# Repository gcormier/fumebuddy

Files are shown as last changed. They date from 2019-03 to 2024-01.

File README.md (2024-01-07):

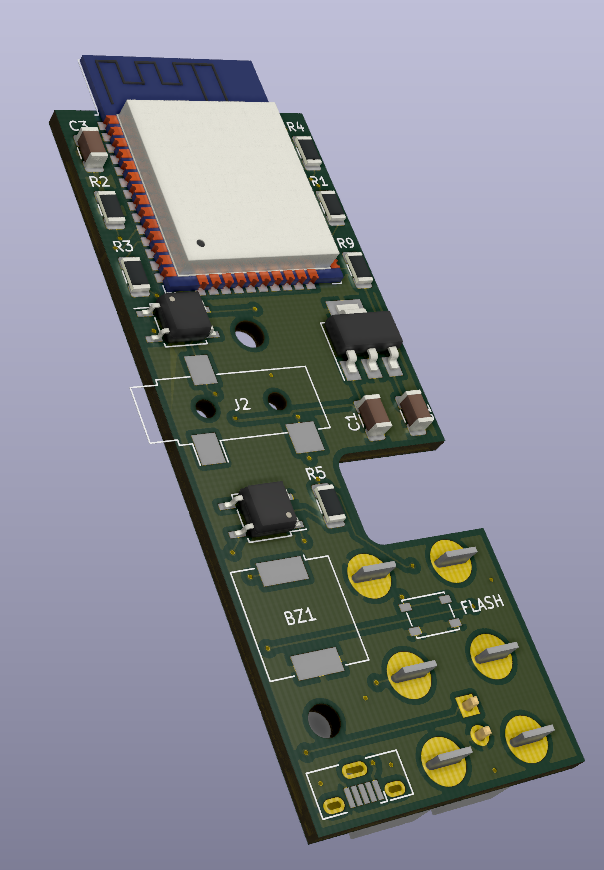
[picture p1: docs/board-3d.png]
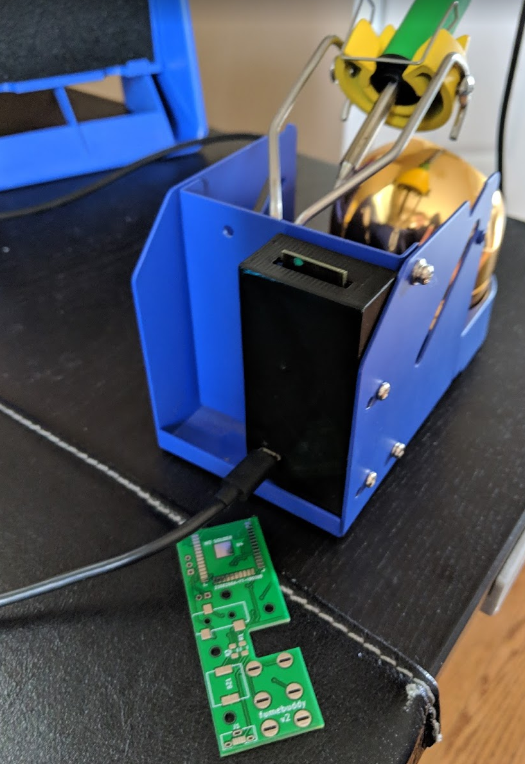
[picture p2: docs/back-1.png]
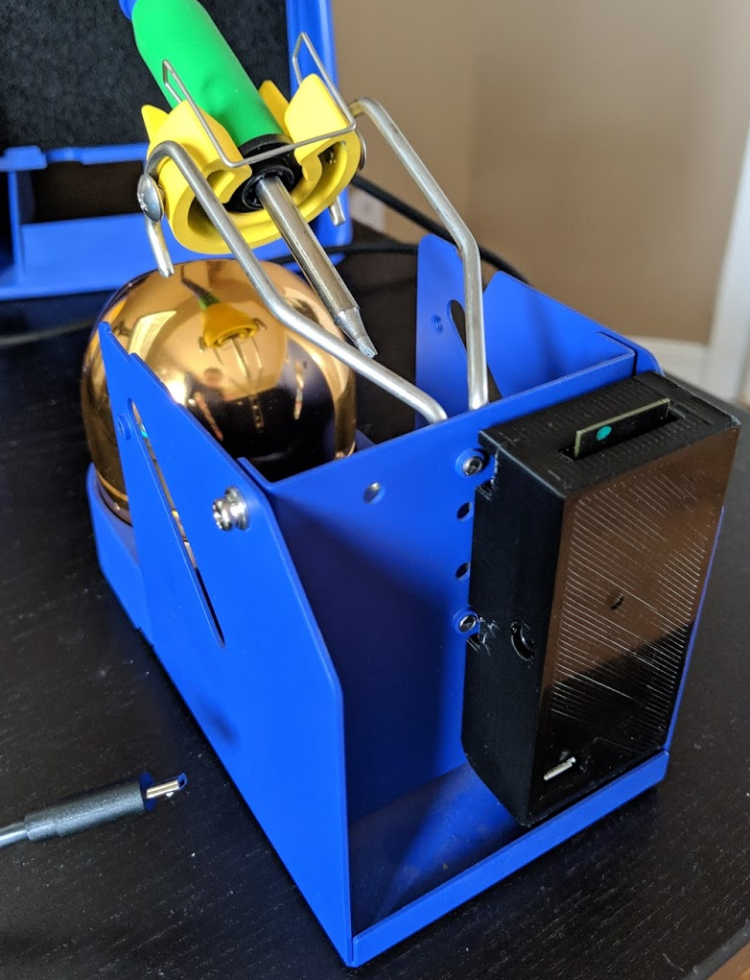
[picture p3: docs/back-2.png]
  

# FumeBuddy
FumeBuddy is an ESP32 replacement for the switch housing on the Hakko FX-950, FX-951 and FX-952. Out of the box, it was designed to toggle a fume extractor via a smart switch flashed with [Tasmota](https://tasmota.github.io/docs/#/). It is powered via USB, which allows it to be powered by a battery pack if desired.



## Design Goals
- Easily hacked
- Replace stock housing
- Default behavior when un-powered

## Video
[See FumeBuddy explained and in action](https://www.youtube.com/watch?v=eo5WyHWy1So)

## Hardware Installation
- Remove the old housing
- Transfer the spring from the old housing to the new housing
- Install using the old screws
- If you'd like the manual capacitive touch function and did not order it, you can solder a single wire to the appropriate jumper

## Configuration
FumeBuddy now uses [esphome](https://esphome.io/index.html). You don't need Home Assistant or any sort of smart home. It merely eliminates the need for me to do any custom coding.

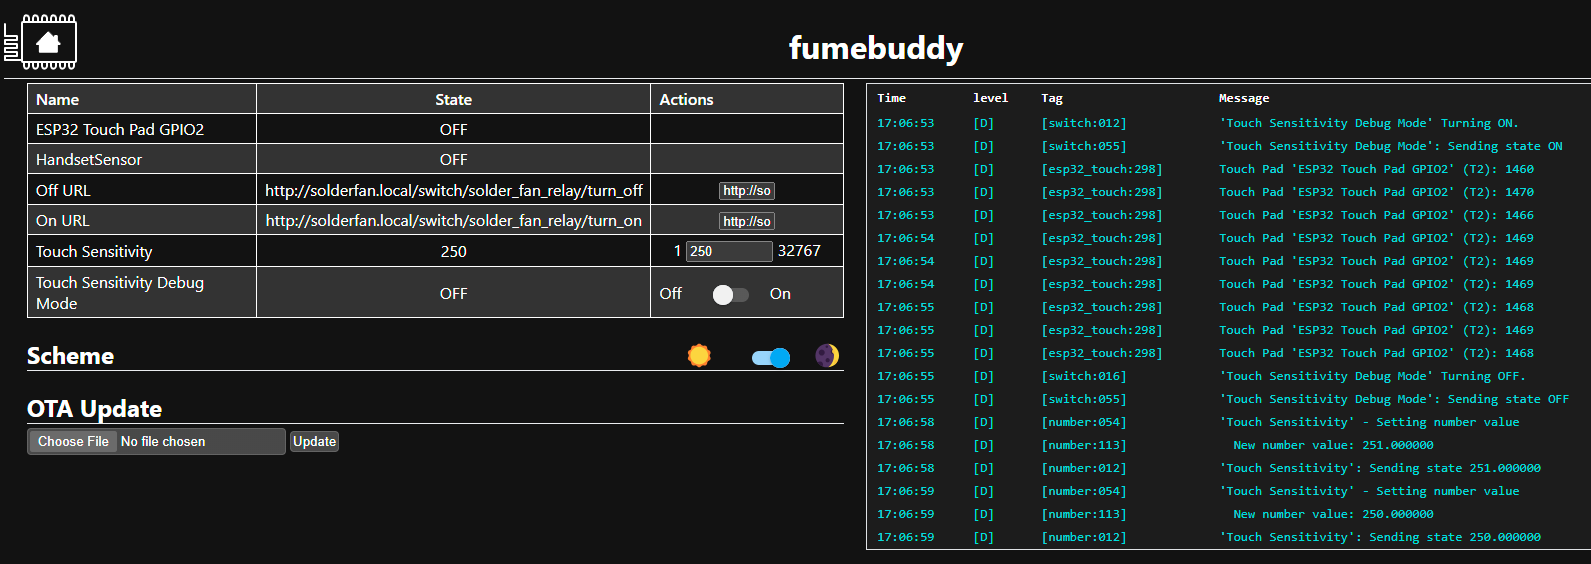
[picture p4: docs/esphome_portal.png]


When you plug in the device, it will create it's own WiFi access point named `FumebuddyFallback` (Password is `fumebuddy`). You
can connect to this and it will redirect you to a captive portal where you can enter your WiFi credentials. Once you do this, it will reboot and connect to your WiFi. You can then access it via the IP address it was assigned by your router.

Accessing it via the IP address will give you a web interface where you can configure the device. Notably the 2 URL's that should be called when the iron is lifted and put back down.

The touch sensor threshold can be adjusted. The default is 250, but you can enable the sensitivity debug mode and view the output
in the web console to see which value works best for you.

## Operation
- If FumeBuddy is NOT powered, the iron will work as it did before with sleep function
- If FumeBuddy is powered via the 5V USB port, it will work based on what is programmed. By default, it will turn the plug ON when the iron is lifted. It will turn the plug OFF 5 seconds after the iron is put back
- Manual on/off can be by touching and holding the capacitive wire on top of the housing. It will keep the fan on until you touch it again.

## Pricing
The BOM cost alone for the product is around 23USD, which is rather expensive. I order **genuine** parts from 1st party distributors in Canada, which in this case includes Omron switches, solid state relays and the ESP32. I did not go cheap on this as owners of Hakko's are likely looking for quality components throughout. The rest includes my labor costs to assembly, flash and test the unit. As it is open sourced, you are welcome to build your own! You can cheap out on some components if you'd like. Knockoff relays and omitting the audio buzzer will save you a few dollars.

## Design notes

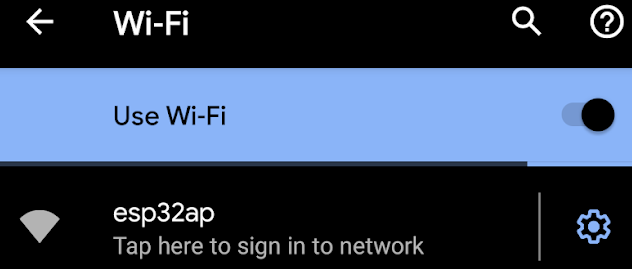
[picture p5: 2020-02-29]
docs/esp32ap-signin.png

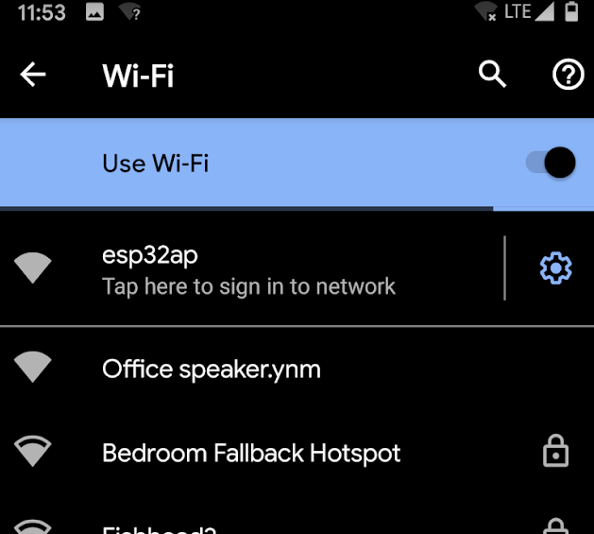
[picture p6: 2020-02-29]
docs/esp32ap.png

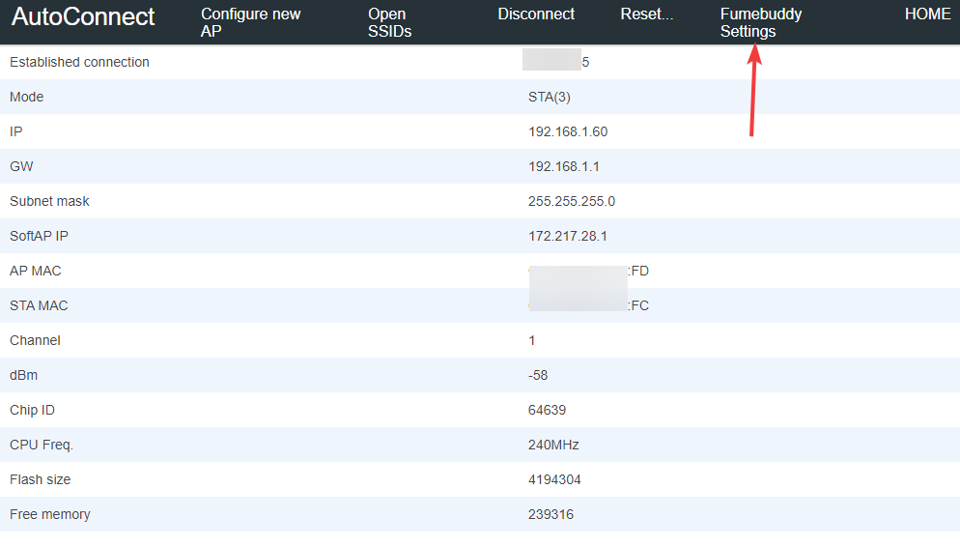
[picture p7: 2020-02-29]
docs/tasmota_1.png

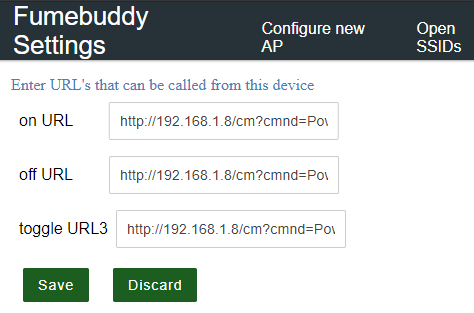
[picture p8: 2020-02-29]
docs/tasmota_2.png

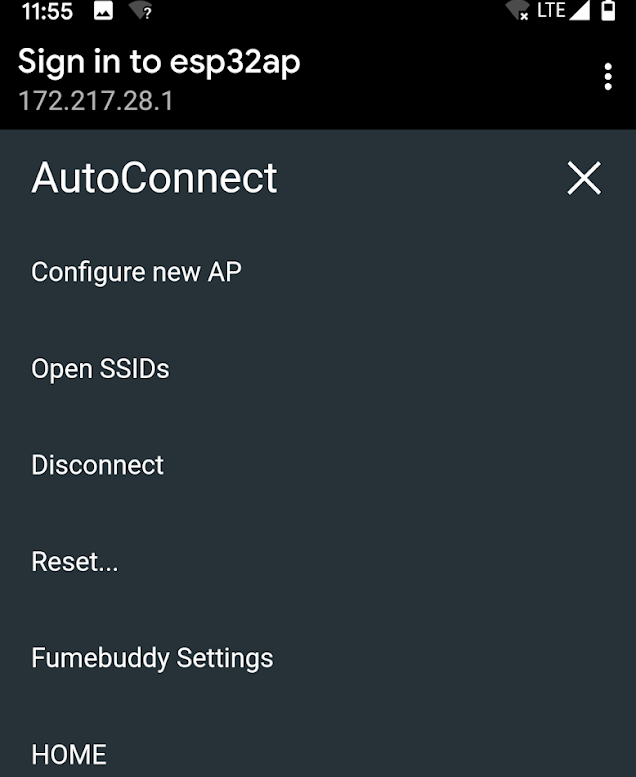
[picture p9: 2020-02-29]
docs/esp32-setting.png

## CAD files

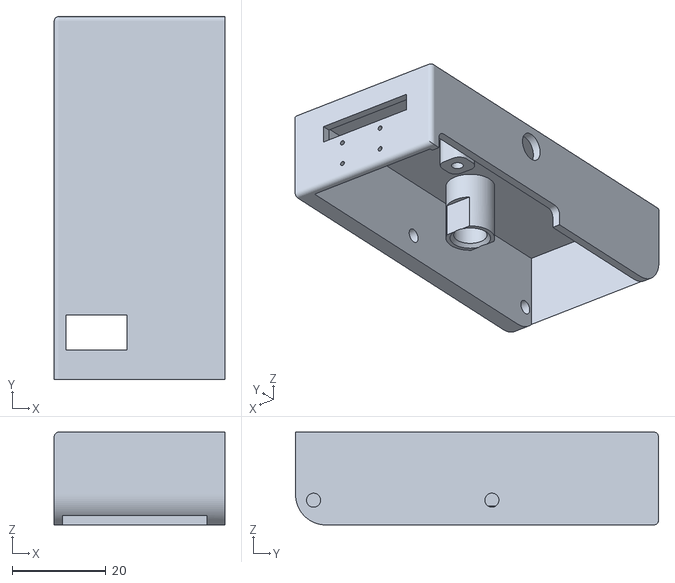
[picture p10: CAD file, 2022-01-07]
Case.stl
36.3 x 77.4 x 19.8

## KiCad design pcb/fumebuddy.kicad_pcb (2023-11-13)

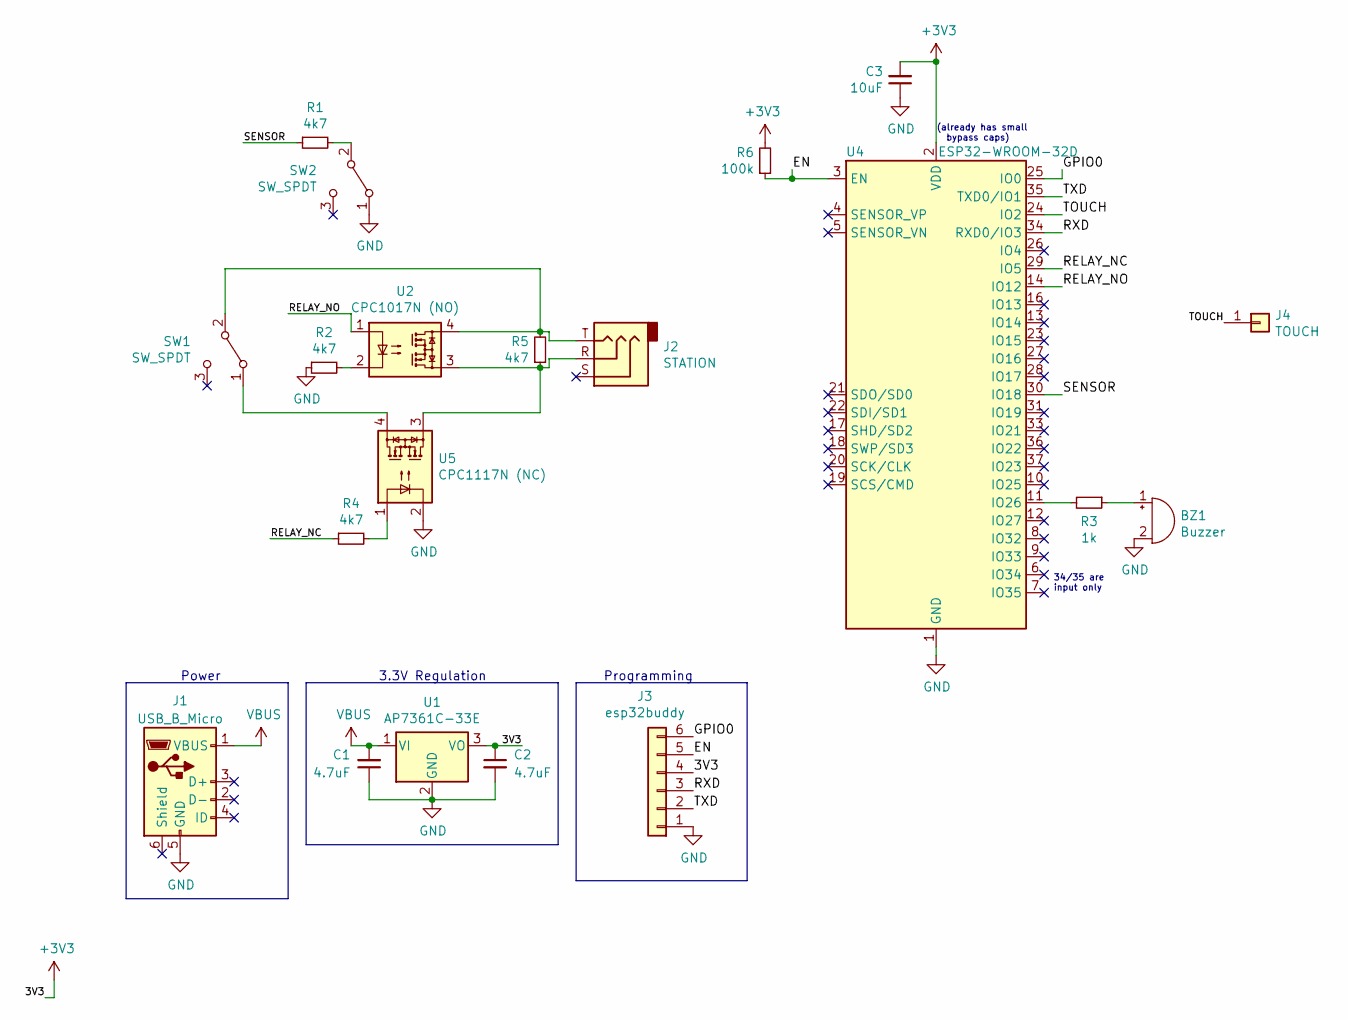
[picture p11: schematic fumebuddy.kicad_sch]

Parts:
BZ1: Buzzer; Buzzer_CUI_CPT-9019S-SMT
C1, C2: 4.7uF; C_1206_3216Metric
C3: 10uF; C_1206_3216Metric
J1: USB_B_Micro; USB_Micro-B_Molex-105133-0001
J2: STATION; Jack_3.5mm_CUI_SJ-3523-SMT_Horizontal
J3: esp32buddy; PinHeader_1x06_P2.54mm_Vertical
J4: TOUCH; PinHeader_1x01_P2.54mm_Vertical
R1, R2, R4, R5: 4k7; R_1206_3216Metric
R3: 1k; R_1206_3216Metric
R6: 100k; R_1206_3216Metric
SW1, SW2: SW_SPDT; OMRON_SS-01-E
U1: AP7361C-33E; SOT-223-3_TabPin2
U2: CPC1017N (NO); SOP-4_3.8x4.1mm_P2.54mm
U4: ESP32-WROOM-32D; ESP32-WROOM-32
U5: CPC1117N (NC); SOP-4_3.8x4.1mm_P2.54mm

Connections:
+3V3: C2.1, C3.2, J3.4, R6.2, U1.3 (VO), U4.2 (VDD)
/EN: J3.5, R6.1, U4.3 (EN)
/GPIO0: J3.6, U4.25 (IO0)
/RELAY_NC: R4.1, U4.29 (IO5)
/RELAY_NO: U2.1, U4.14 (IO12)
/RXD: J3.3, U4.34 (RXD0/IO3)
/SENSOR: R1.1, U4.30 (IO18)
/TOUCH: J4.1, U4.24 (IO2)
/TXD: J3.2, U4.35 (TXD0/IO1)
GND: BZ1.2 (+), C1.1, C2.2, C3.1, J1.5 (GND), J3.1, R2.1, SW2.1 (A), U1.2 (GND), U4.1 (GND), U4.15 (GND), U4.38 (GND), U4.39 (GND), U5.2
unnamed: BZ1.1 (-), R3.1
unnamed: J2.R, R5.1, U2.3, U5.3
unnamed: R2.2, U2.2
unnamed: R4.2, U5.1
unnamed: SW1.1 (A), U5.4
unnamed: J2.T, R5.2, SW1.2 (B), U2.4
unnamed: R1.2, SW2.2 (B)
unnamed: R3.2, U4.11 (IO26)
VBUS: C1.2, J1.1 (VBUS), U1.1 (VI)

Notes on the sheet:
Programming
Power
3.3V Regulation
34/35 are input only
(already has small bypass caps)

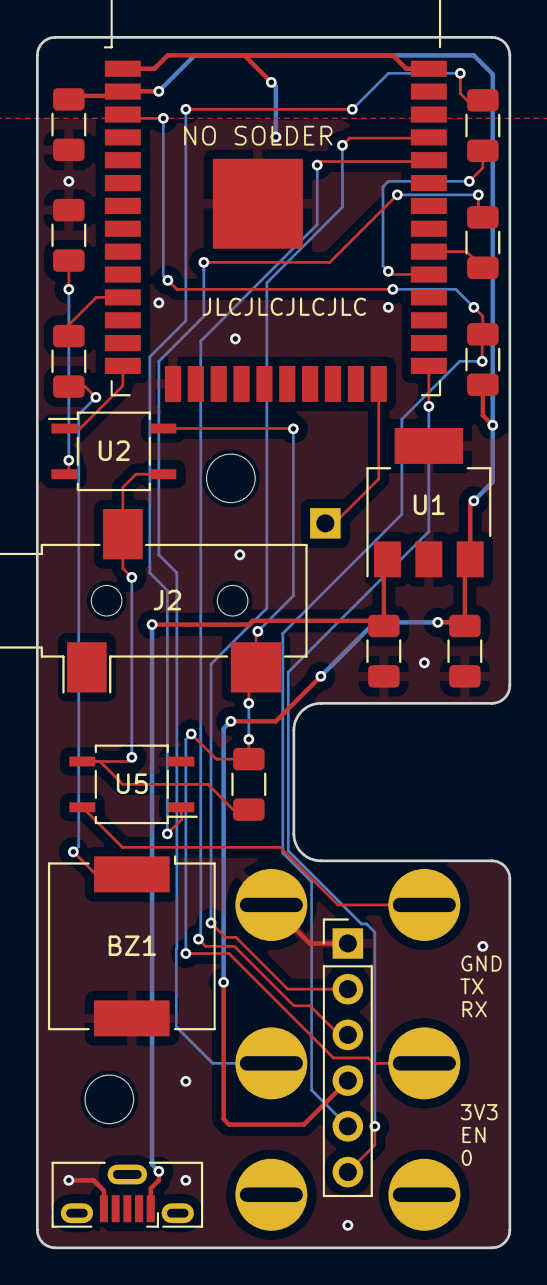
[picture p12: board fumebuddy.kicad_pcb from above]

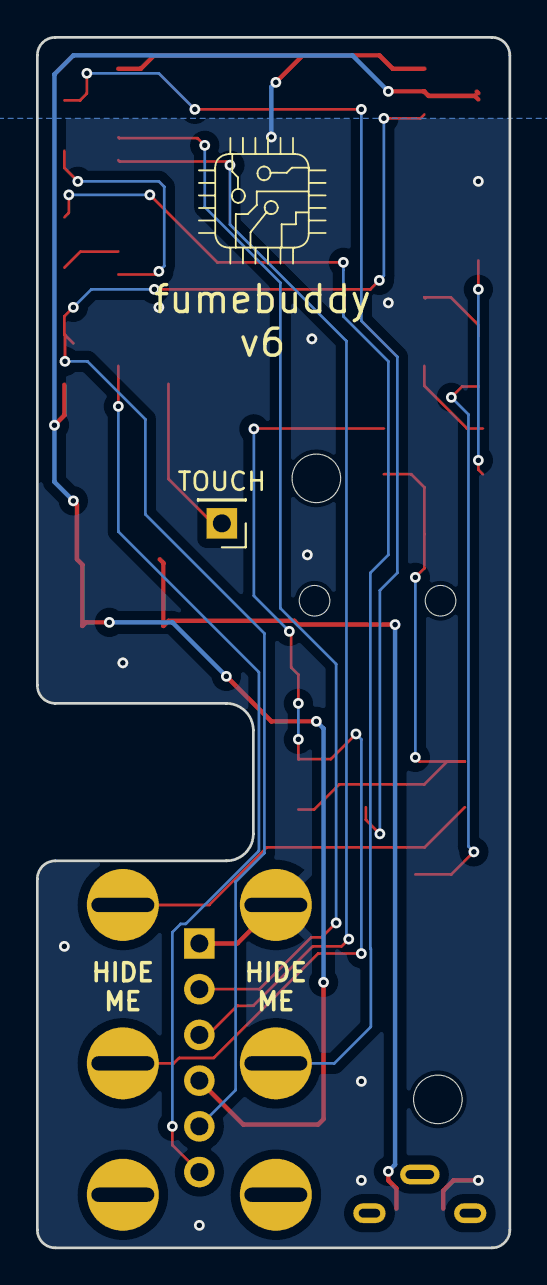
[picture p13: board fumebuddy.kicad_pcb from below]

Board: 2 copper layers, 26.2 x 67.2 mm, 20 parts (3 on the bottom side), 19 nets.

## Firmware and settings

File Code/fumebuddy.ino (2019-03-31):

#include <WiFi.h>
#include <WebServer.h>
#include <SPIFFS.h>
#include <FS.h>
#include <AutoConnect.h>
#include <ArduinoOTA.h>
#include <HTTPClient.h>
#include "espurna.h"

#define PARAM_FILE        "/param.json"
#define AUX_SETTING_URI   "/espurna_setting"
#define AUX_SAVE_URI      "/espurna_save"
#define AUX_CLEAR_URI     "/espurna_clear"

#define PIN_SENSOR      17
#define PIN_RELAY_AUX   14
#define PIN_RELAY_NC    5
#define PIN_RELAY_NO    12
#define PIN_BUZZER      26
#define OFFHOOK         HIGH
#define ONHOOK          LOW

#define ONHOOK_DELAY     5L   // Delay before turning off in seconds

enum class HookState {
  STATE_OFFHOOK,      // Off hook
  STATE_ONHOOK_READY, // Ready for On Hook
  STATE_ONHOOK        // On hook
};

typedef WebServer WiFiWebServer;

bool hookState = ONHOOK;
uint32_t currentMillis = 0;
uint32_t onHookMillis = 0;

HTTPClient http;
WebServer server;
AutoConnect Portal(server);
AutoConnectConfig acConfig;

String serverName;
String apiKey;
HookState currentState;

void setup()
{
  pinMode(PIN_RELAY_NO, OUTPUT);
  pinMode(PIN_RELAY_NC, OUTPUT);
  pinMode(PIN_SENSOR, INPUT_PULLUP);
  pinMode(PIN_RELAY_AUX, OUTPUT);

  digitalWrite(PIN_RELAY_NC, HIGH);
  currentMillis = millis();

  ledcSetup(0, 1E5, 12);
  ledcAttachPin(PIN_BUZZER, 0);

  ledcWriteNote(0, NOTE_C, 5);
  delay(125);
  ledcWriteNote(0, NOTE_E, 5);
  delay(125);
  ledcWriteNote(0, NOTE_G, 5);
  delay(125);
  ledcWrite(0, 0);
    
  Serial.begin(115200);

  ArduinoOTA
    .onStart([]() {
    String type;
    if (ArduinoOTA.getCommand() == U_FLASH)
      type = "sketch";
    else // U_SPIFFS
      type = "filesystem";

    // NOTE: if updating SPIFFS this would be the place to unmount SPIFFS using SPIFFS.end()
    Serial.println("Start updating " + type);
  })
    .onEnd([]() {
    Serial.println("\nEnd");
  })
    .onProgress([](unsigned int progress, unsigned int total) {
    Serial.printf("Progress: %u%%\r", (progress / (total / 100)));
  })
    .onError([](ota_error_t error) {
    Serial.printf("Error[%u]: ", error);
    if (error == OTA_AUTH_ERROR) Serial.println("Auth Failed");
    else if (error == OTA_BEGIN_ERROR) Serial.println("Begin Failed");
    else if (error == OTA_CONNECT_ERROR) Serial.println("Connect Failed");
    else if (error == OTA_RECEIVE_ERROR) Serial.println("Receive Failed");
    else if (error == OTA_END_ERROR) Serial.println("End Failed");
  });

  SPIFFS.begin(true);

  
  acConfig.apid = "ESP-fumebuddy";
  acConfig.homeUri = "/";
  acConfig.portalTimeout = 300; // Timeout after 5 minutes
  Portal.config(acConfig);
  
  AutoConnectAux *espurna_setting = Portal.aux("/espurna");
  Portal.load(FPSTR(AUX_espurna_settings));

  Portal.on(AUX_SETTING_URI, loadParams);
  Portal.on(AUX_SAVE_URI, saveParams);
  //Portal.on("/", handleRoot);
  
  Portal.begin();
  ArduinoOTA.begin();

  
  //AutoConnectInput&     ac_serverName = espurna_setting->getElement<AutoConnectInput>("espurnaserver");
  //AutoConnectInput&     ac_apiKey = espurna_setting->getElement<AutoConnectInput>("apikey");
  
  //if (ac_serverName.value.length())
//    serverName = ac_serverName.value;
  //apiKey = ac_apiKey.value;
  
  

  //offHook();
  //delay(1000);
  hookState = OFFHOOK;
  onHook();
}

void loop()
{
  currentMillis = millis();
  bool currentHookStatus = readHookState();

  if (currentHookStatus == OFFHOOK)
    offHook();
  else if (currentHookStatus == ONHOOK)
    onHook();


  if (hookState == ONHOOK && onHookMillis < currentMillis && onHookMillis > 0)
  {
    stopDevice();
    onHookMillis = 0;
  }

  if (WiFi.status() == WL_CONNECTED)
  {
    ArduinoOTA.handle();
  }
  Portal.handleClient();
}

bool readHookState()
{
  return digitalRead(PIN_SENSOR);
}



void offHook()
{
  if (hookState == ONHOOK)
  {
    digitalWrite(PIN_RELAY_NO, LOW);
    hookState = OFFHOOK;
    startDevice();
    onHookMillis = 0;
    Serial.println("Going off hook");
  }
}

void onHook()
{
  if (hookState == OFFHOOK)
  {
    digitalWrite(PIN_RELAY_NO, HIGH);
    hookState = ONHOOK;
    //stopDevice();
    onHookMillis = millis() + (ONHOOK_DELAY * 1000L);
    Serial.println("Going on hook");
  }
}

void startDevice()
{
  http.begin("http://" + serverName + "/api/relay/0?apikey=" + apiKey + "&value=1");
  http.GET();
  http.end();
}

void stopDevice()
{
  http.begin("http://" + serverName + "/api/relay/0?apikey=" + apiKey + "&value=0");
  http.GET();
  http.end();
}

void toggleDevice()
{
  http.begin("http://" + serverName + "/api/relay/0?apikey=" + apiKey + "&value=2");
  http.GET();
  http.end();
}

// Load parameters saved with  saveParams from SPIFFS into the
// elements defined in /mqtt_setting JSON.
String loadParams(AutoConnectAux& aux, PageArgument& args)
{
  (void)(args);
  File param = SPIFFS.open(PARAM_FILE, "r");
  if (param)
  {
    if (aux.loadElement(param))
      Serial.println(PARAM_FILE " loaded");
    else
      Serial.println(PARAM_FILE " failed to load");
    param.close();
  }
  else
  {
    Serial.println(PARAM_FILE " open failed");
    Serial.println("If you get error as 'SPIFFS: mount failed, -10025', Please modify with 'SPIFFS.begin(true)'.");
  }
  return String("");
}


String saveParams(AutoConnectAux& aux, PageArgument& args)
{
  AutoConnectAux*   espurna_setting = Portal.where();

  AutoConnectInput& espurnaserver = espurna_setting->getElement<AutoConnectInput>("espurnaserver");
  serverName = espurnaserver.value;
  serverName.trim();

  AutoConnectInput& apikey = espurna_setting->getElement<AutoConnectInput>("apikey");
  apiKey = apikey.value;
  apiKey.trim();

  File param = SPIFFS.open(PARAM_FILE, "w");
  espurna_setting->saveElement(param, { "espurnaserver", "apikey" });
  param.close();
  
  AutoConnectText&  echo = aux.getElement<AutoConnectText>("parameters");
  echo.value = "Server: " + serverName;
  echo.value += "API Key: " + apiKey + "<br>";
  
  return String("");
}

void handleRoot()
{
  String  content =
    "<html>"
    "<head>"
    "<meta name=\"viewport\" content=\"width=device-width, initial-scale=1\">"
    "</head>"
    "<body>"
    "<iframe width=\"450\" height=\"260\" style=\"transform:scale(0.79);-o-transform:scale(0.79);-webkit-transform:scale(0.79);-moz-transform:scale(0.79);-ms-transform:scale(0.79);transform-origin:0 0;-o-transform-origin:0 0;-webkit-transform-origin:0 0;-moz-transform-origin:0 0;-ms-transform-origin:0 0;border: 1px solid #cccccc;\" src=\"https://thingspeak.com/channels/454951/charts/1?bgcolor=%23ffffff&color=%23d62020&dynamic=true&type=line\"></iframe>"
    "<p style=\"padding-top:5px;text-align:center\">" AUTOCONNECT_LINK(COG_24) "</p>"
    "</body>"
    "</html>";

  WiFiWebServer&  webServer = Portal.host();
  webServer.send(200, "text/html", content);
}

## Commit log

2019-03-31 Initial release.
    [fumebuddy.kicad_pcb, fumebuddy.sch]
2019-03-31 should be v3
    [fumebuddy.kicad_pcb]
2019-10-04 Maybe update to new AutoConnect format?
    [fumebuddy.kicad_pcb]
2019-12-15 Move to one-sided for all SMD components
    [fumebuddy.kicad_pcb]
2019-12-16 finalize singleside
    [fumebuddy.kicad_pcb]
2020-01-01 Change GPIO25 to 27 to use touch functionality
    [fumebuddy.sch]
2020-01-02 Touch support to toggle fan on/off
2020-01-02 Update schematic to use touch pin
    [fumebuddy.kicad_pcb]
2020-07-03 v5 final sent to fab
    [fumebuddy.kicad_pcb, fumebuddy.sch]
2020-07-03 Update ibom
    [fumebuddy.kicad_pcb]
2020-07-16 Change programming header, no more flash header
    [fumebuddy.kicad_pcb, fumebuddy.sch]
2021-10-25 update code to new GPIO pin for v6
2023-11-13 fix case
    [fumebuddy.kicad_pcb, fumebuddy.kicad_sch]
2023-11-13 fix case2
    [fumebuddy.kicad_pcb, fumebuddy.kicad_sch]
